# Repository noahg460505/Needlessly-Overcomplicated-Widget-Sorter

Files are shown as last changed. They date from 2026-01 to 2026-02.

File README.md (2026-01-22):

# Needlessly-Overcomplicated-Widget-Sorter

Portfolio for our widget sorter project

# Table of Contents

1. [Acknowledgments](https://github.com/noahg460505/Needlessly-Overcomplicated-Widget-Sorter/blob/main/README.md#acknowledgements)
2. [Setup](https://github.com/noahg460505/Needlessly-Overcomplicated-Widget-Sorter/blob/main/README.md#setup)
3. [Sorting](https://github.com/noahg460505/Needlessly-Overcomplicated-Widget-Sorter/blob/main/README.md#sorting)
4. [AI Acknowledgment](https://github.com/noahg460505/Needlessly-Overcomplicated-Widget-Sorter/blob/main/README.md#ai-acknowledgement)

# Acknowledgements

This widget sorter was designed, built, and tested by Noah Grimes, Yarema Mushkevych, and Markus Walker, with help from Keegan Smit, Nolan Thurman, and Claude Sonnet 4.5. Equipment was provided by Mr. Small and Mr. Cronk. 

Machining was done using equipment in the Southridge High School Engineering Lab, including

- A Carvera CNC
- A Prusa Mk3 3D-Printer
- A Laser Cutter

All CAD was done in OnShape 

All Arduino and C++ code was done in the latest version of both the Windows edition of the desktop IDE and the Linux edition of the desktop IDE. The Python code was done in Thonny on a Raspberry Pi 3B+, which was "acquired" from Mr. Cronk.

The Linear Actuator and Loctite used in this project were acquired through out-of-pocket funds. 

# Setup

(how to get this to work, hopefully)

Ensure that all LEDs on the Arduino are connected properly. This can be tested by uploading the code to the Arduino; if the wiring is successful, the LEDs should all light up. 

A standard microUSB should be connected from the Pi at port `USB0` into the Arduino. From the power strip, a 12v power supply should be connected. 
The Pi should be connected to a keyboard and monitor. We recommend using KDE Connect so that coding can be done from another device and copy-pasted into the Pi, as the Pi 3B+ is a bit slow for using an IDE, even one as simple as Thonny.

# Sorting

Start by turning on the Arduino and ensuring that it is fully active. Let the Arduino dispense one widget into the capture zone, and then take it out. Run the Python command to execute the widget sorting program. If the camera fails to connect, rerun the program. Once the Arduino is on, there is no need to restart it or turn it off. It is recommended to shine a light on the backside of the capture zone to minimize sorting errors. 

# AI Acknowledgement

The vast majority of [the Python code](code/widget_inspector.py) for this project was done by Claude Sonnet 4.5, with edits made by Noah Grimes and Keegan Smit.

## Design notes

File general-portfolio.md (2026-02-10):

# General Portfolio
This is the shared portfolio for all of us, containing the parts of the portfolio that don't differ between members of the group

## A description of the project requirements and constraints
The goal for this project was to make a device which would differentiate, sort, and count widgets based on if they have holes or not. [Good widgets](CAD/stl-files/good-widget.stl) are 3-dimensional rectangular shapes that have an off centered hole going through them and bad widgets are missing a hole. We have to load 5 good and 5 bad widgets at random and the sorter needs to count them, sort them, and know when it is done counting them after a single button press. 

## An outline of your project
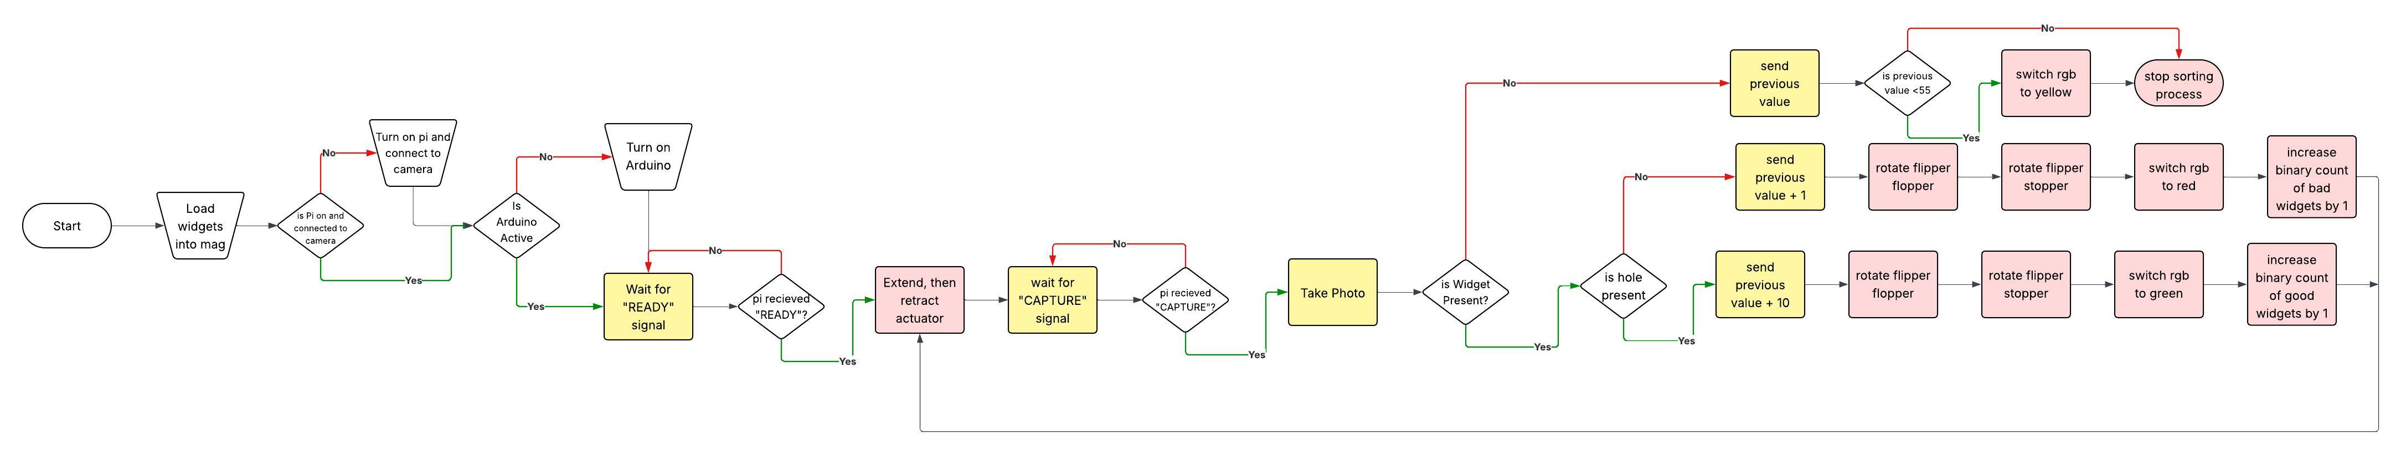
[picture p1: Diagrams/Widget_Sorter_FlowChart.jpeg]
Flowchart


## A wiring diagram - this could be hand drawn, made using software, a tinkerCAD link, etc

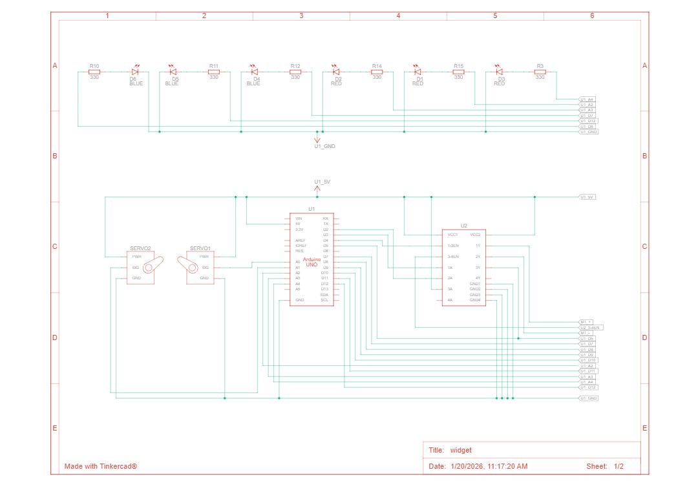
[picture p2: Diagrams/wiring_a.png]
Wiring Diagram A


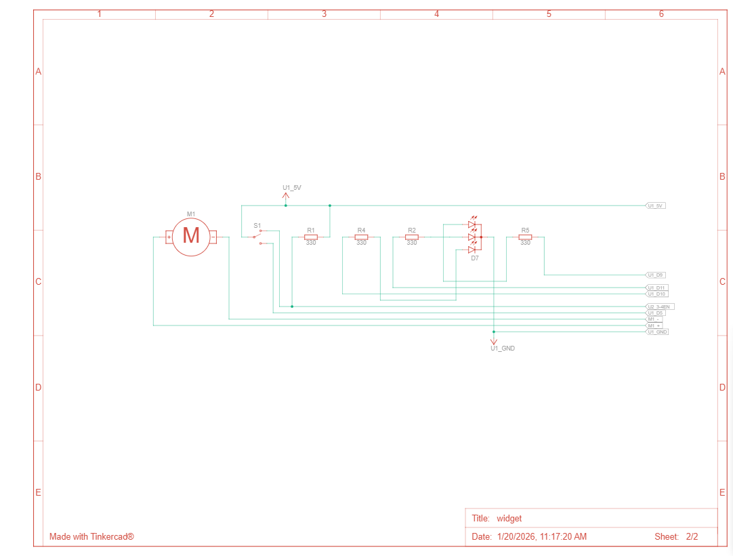
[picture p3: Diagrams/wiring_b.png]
Wiring Diagram B


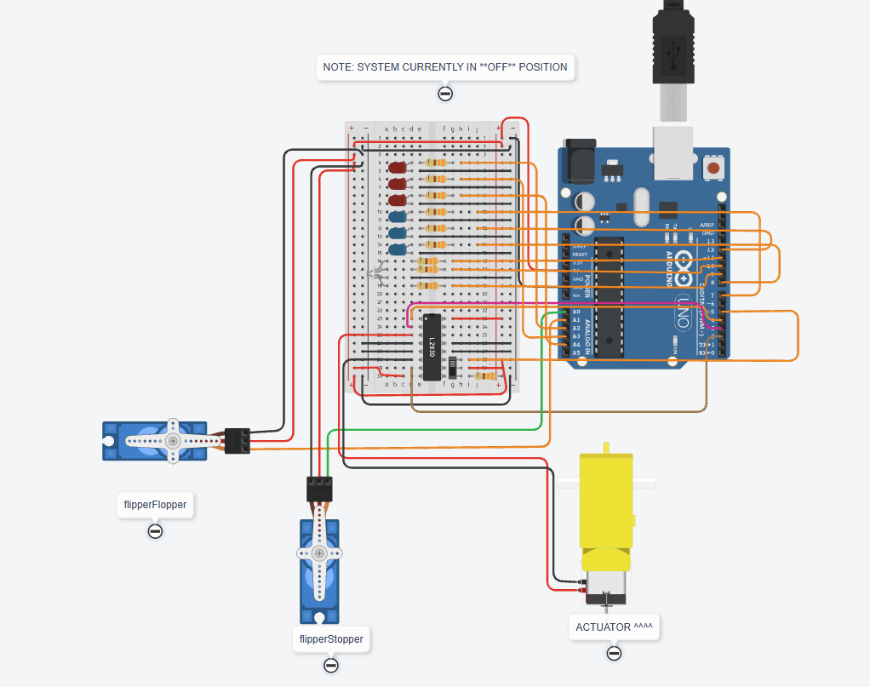
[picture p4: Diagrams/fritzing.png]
Fritzing


## A set of mechanical drawings showing components, assembly, and hardware.
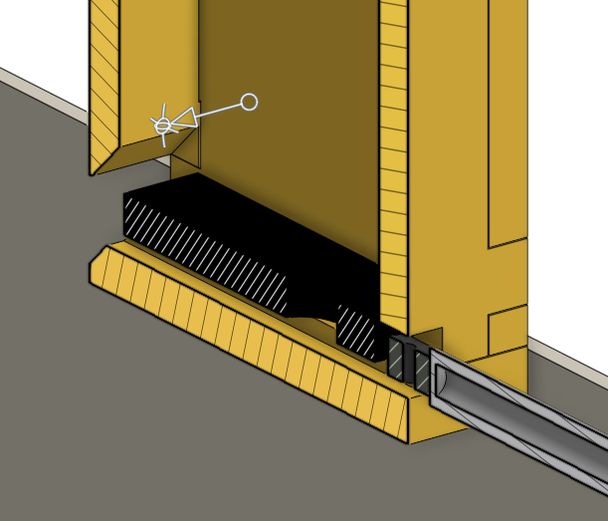
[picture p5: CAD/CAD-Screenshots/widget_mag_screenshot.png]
Widget Action


Widget MagV2.3

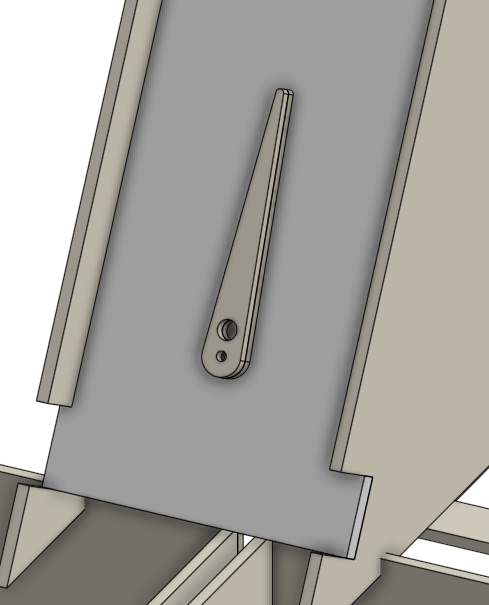
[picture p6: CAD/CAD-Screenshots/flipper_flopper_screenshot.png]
Flipper Flopper


Flipper Stopper

## A parts list
- Camera 
- Raspberry Pi
- Keyboard 
- Mouse
- Monitor
- [100mm Linear actuator](https://www.amazon.com/Electric-High-Speed-sec-Weight-Intelligent-Automation/dp/B07ZJ46947/ref=sr_1_14?th=1) 
- 2 Servo Motors
- Mounting hardware (various metric bolts)
- PLA for the prints
- 3mm wood or mdf for structure
- Arduino
- Breadboard 
- Switch 
- 3 red and 3 blue LED
- RGB LED
- Switch 
- Motor controller
- Many wires w/ Dupont connectors

## A program including header and comments
[Widget Detection Pi Code](code/widget_inspector.py)  
[Arduino Code](code/motor_control.ino)

## Any CAD models used in the project - include screen captures and a link to your drawing files
### [Onshape Link](https://cad.onshape.com/documents/1959d45d93e06fd605dded79/w/4b29a523473d3687186c98d2/e/b105ef3a0426237b67d9fdd4)  
[STL Files](CAD/stl-files)  
[Laser Cut Files](CAD/laser-files)  
[CNC Files](CAD/cnc-files)

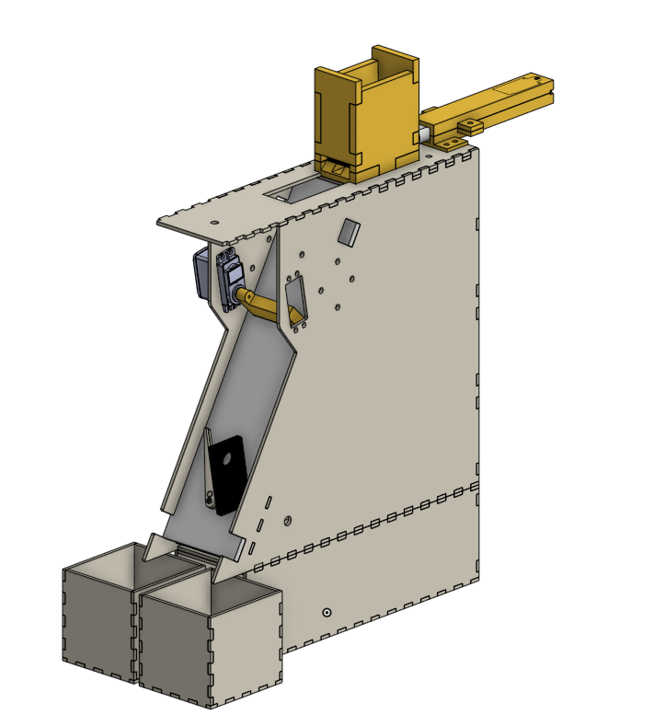
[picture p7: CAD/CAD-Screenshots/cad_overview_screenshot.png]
CAD Overview


Full Cad

## Photos of the project
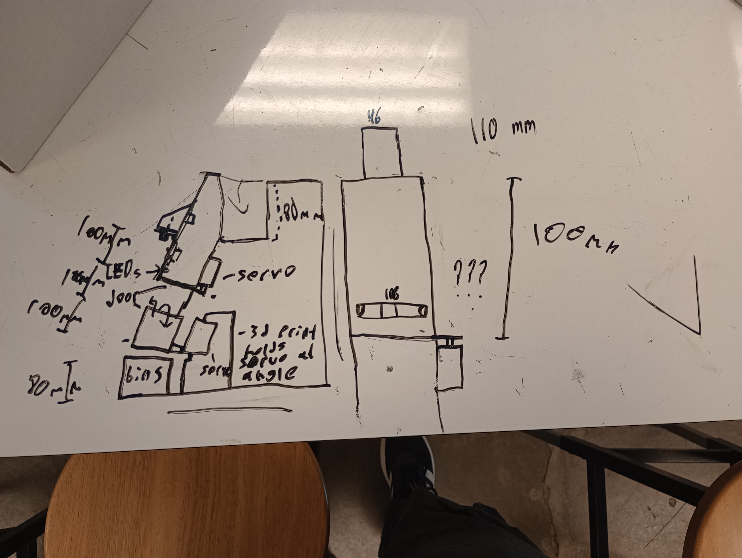
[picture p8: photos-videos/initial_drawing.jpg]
Starting Plan


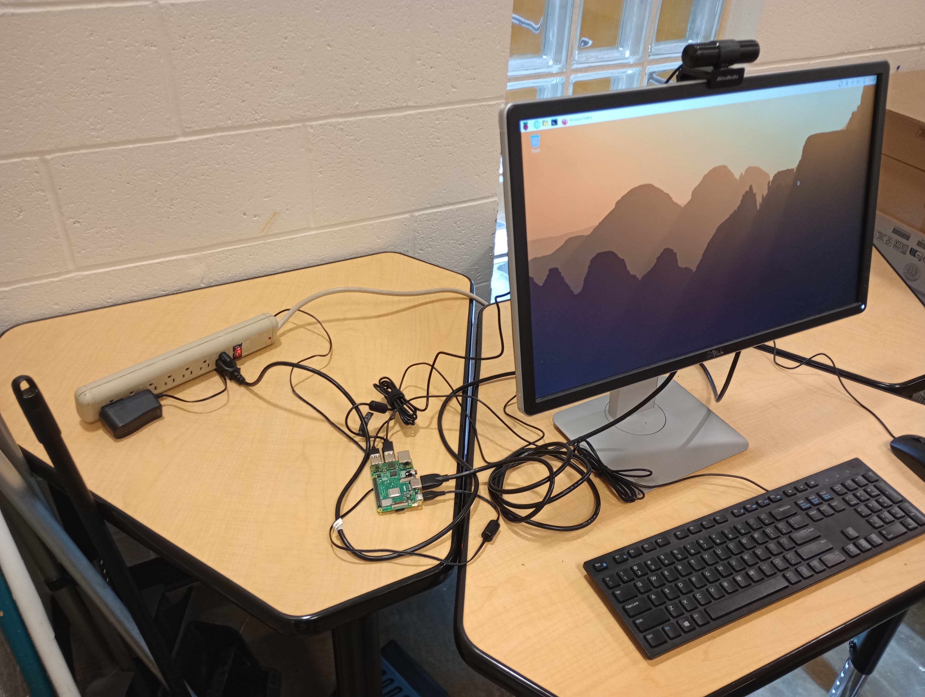
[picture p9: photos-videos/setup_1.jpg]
Pi Setup


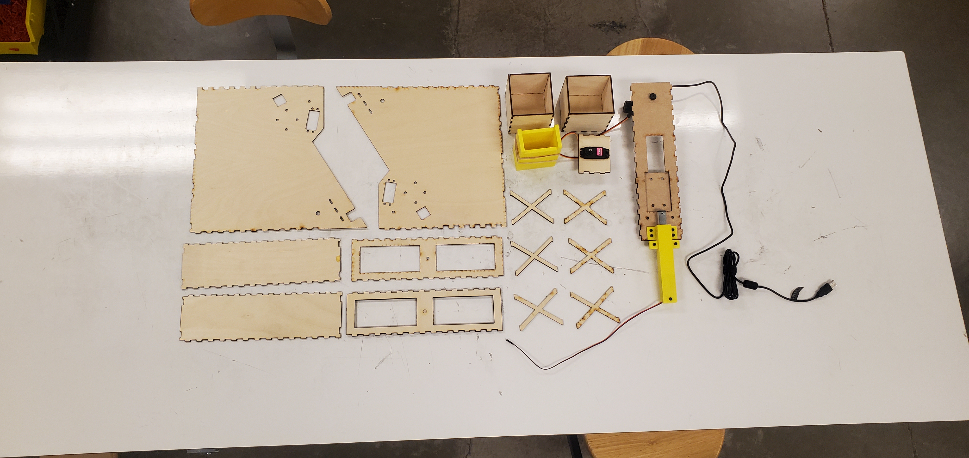
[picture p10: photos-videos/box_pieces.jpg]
Parts Laid Out


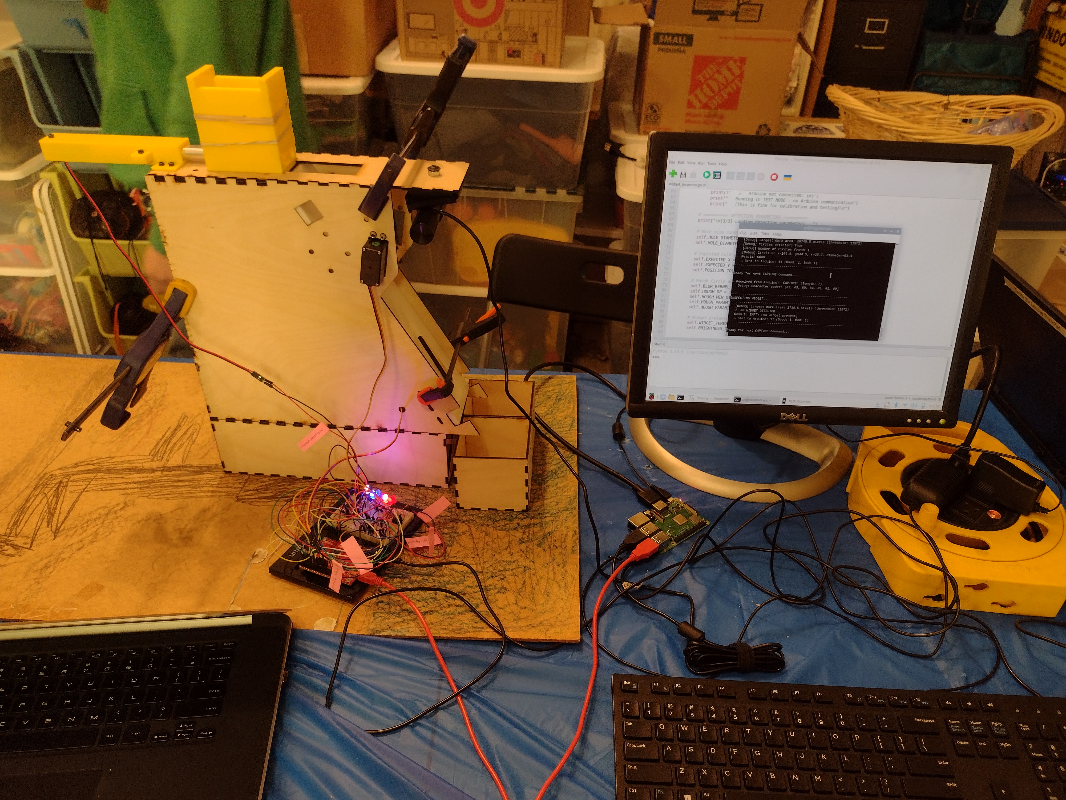
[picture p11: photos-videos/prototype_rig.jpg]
Prodotype Rig


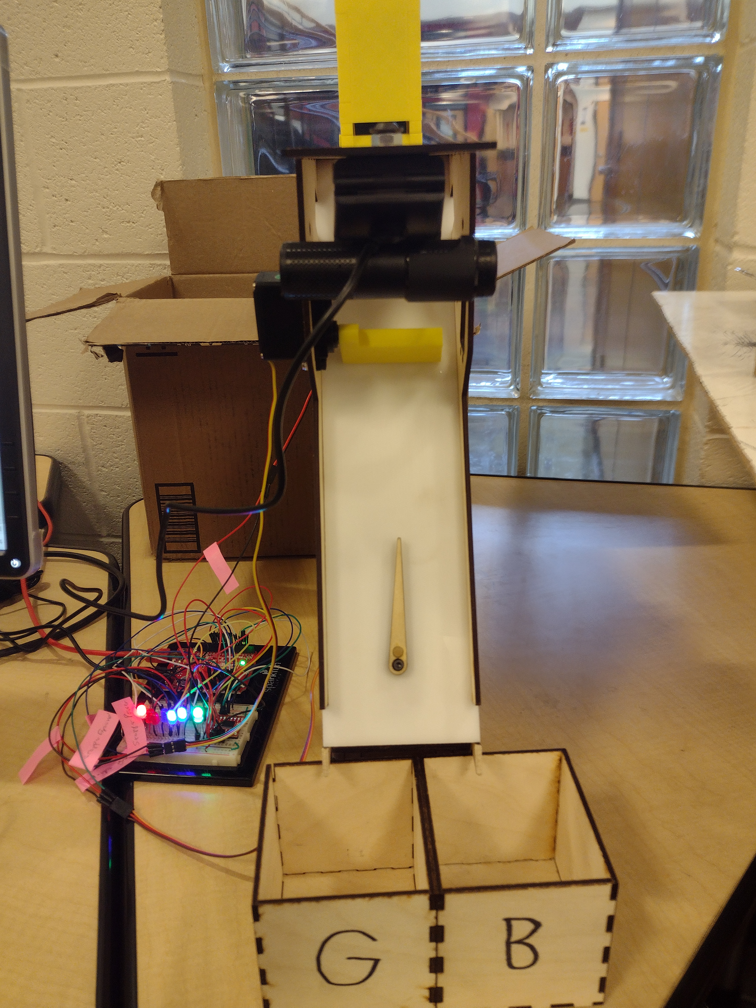
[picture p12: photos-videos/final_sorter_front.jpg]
Final Rig

## A video of it working

Prototype Test

## Reflections
[Markus Walker](Markus/markus-walker-reflection.md)

[Noah Grimes](Noah/noah-grimes-reflection.md)

[Yarema Mushkevych](Yarema/yarema-mushkevych-reflection.md)

## Any needed citations of sources

[Tinkercad Circuits Designer](https://tinkercad.com/circuits)

[Claude Sonnet](https://claude.ai)

[Arduino Forum](https://forum.arduino.cc)

[Onshape](https://cad.onshape.com)

[Download link for Arduino IDE](https://support.arduino.cc/hc/en-us/articles/360019833020-Download-and-install-Arduino-IDE)

[Thonny Download](https://thonny.org/)

[KDE Connect Download](https://kdeconnect.kde.org/download.html)

[Python Download](https://www.python.org/)

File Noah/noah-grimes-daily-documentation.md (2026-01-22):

# Day 0
## 11/12/25
Today, we began some basic planning, I was still working on my box, but we were working on coming up with ideas. We decided that instead of doing something BORING and SIMPLE, we would use a webcam attached to a Raspberry Pi and do image recognition of good and bad widgets. While this is more complicated and requires more programming, it will actually make the mechanics significantly easier.  
Initial Drawing  

# Day 1
## 11/14/25
Yesterday, I flashed a Raspbian ISO onto a microSD card that Cronk gave me, then today I went to Cronk’s classroom to grab a Pi 3B+. Today during class we got a monitor, keyboard, and mouse that were going to be thrown out with the old engineering computers. We set up a little area in the corner of the room with the Pi, monitor, keyboard, and mouse and began working on our project. After all this was done, class was basically over, so we came in during seminar to work. We started with a quick feasibility test, we had Claude Sonnet 4.5 generate some testing code, it worked pretty well, and even better when using a flashlight placed right above the camera, putting the flashlight to the side created shadows that made the recognition unreliable.

# Day 2
## 11/18/25
Today, we had Claude adjust the code so it can also detect if there is a widget there at all, as it would say no widget = bad widget. Its code sucked and it didn’t work, and my Claude free prompts had run out for the day, but because I am a PYTHON PROGRAMMING GOD I fixed the code myself, so now it works, yippee! It can fairly reliably distinguish between good, bad, and no widgets. We also started on CAD, Markus made the magazine and I made a quick widget. During seminar, we got the we got the finished magazine and started to test it, we found you needed to push the widget ALL THE WAY OUT before it would fall.

# Day 3
## 11/20/25
To make the widgets come out easier, we chamfered the edges on the output. We also made the magazine modular so it is faster to print different variants of it.

# Day 4
## 12/1/25
Today, we did a TON more CAD, we found a linear actuator part on the public parts list in Onshape and modified our magazine to fit it. Markus bought a linear actuator that can extend four inches during the break, it should arrive tomorrow.

# Day 5
## 12/3/25
We got the linear actuator, did a ton of testing with it. It doesn’t really work unless you run it at 12v, which is fine, just good to know. Markus began work on a casing for the linear actuator so we can attach it near the front instead of the back. I started work on the ramp itself.

# Day 6
## 12/5/25
Did a bunch more work on the ramp, now have the linear actuator casing, but it doesn’t key in properly in the front, the actuator gets narrower, but casing stays at a constant width. The linear actuator is only attached to the casing in the back, so it needs to be tight in the front to not be able to rotate side-to-side.

# Day 7
## 12/9/25
I realized the side walls were too tall for the MDF sheets, so I made it shorter, and adjusted things a lot. This adjustment took me the vast majority of the class time we had today.

# Day 8
## 12/11/25
Today we tested the linear actuator with the box, but with the top plate so it was at the right height. The actuator was slightly too high and started hitting the wall. We couldn’t just sand the wall a bit to give it more room, because then the actuator would hit both the bottom and the next widget above, instead of JUST the bottom widget. We made these minor corrections and started printing, we didn’t get anything else done today. Yarema and Markus helped me study for a math quiz tomorrow.

# Day 9
## 12/15/25
Today I was struggling wayyyy too much to make finger joints for the sorting bins, so I personally didn’t get much done. Today we also tested the fixed version of widget magazine, the linear actuator no longer collides with it, yippee! During seminar, we started cutting the sorting boxes on the laser cutter, they didn’t finish before the end of seminar.

# Day 10
## 12/17/25
At the beginning of class we got the flipper stopper, which Markus designed). During class, we assembled the sorting bins with wood glue. We also cut out the servo mounting bracket for the flipper flopper. Not much else done this class, we had the OSU engineering presentation today. During seminar, I was able to do the last bits of CAD for the whole structure. I designed some MDF cross members to support the structure, and we got those all cut out on the laser cutter. Virtually everything is now ready to be manufactured and assembled now, yippee!  
CAD Overview

# Day 11
## 12/19/25
Today we just cut out a bunch of the side panels and such on the laser while Yarema finished the code.

# Day 12
## 1/7/26
Today we started gluing the whole structure together and also tried to figure out the CNC to get the ramp cut, we did not get it figured out.

# Day 13
## 1/9/26
We tried to CNC, we spent 20 minutes removing the paper from the acrylic, we then realized that the keying cut by the CNC was not even slightly centered because Markus gave Mr. Small the wrong dimensions >:c

Also everything that can be glued is now glued, the whole structure can stay together (the side panel is just sitting on, since the ramp still needs to be installed).

# Day 14
## 1/13/26
Mr. Small got our ramp cut on the CNC, so today we assembled everything - still without glue - and did some testing. I ran out of time to rewrite the awful AI code, so we just had to have the AI improve it with some modifications, ran out of prompts with completely broken code though, so we came in for seminar and had Keegan help fix it with us (He is much faster at troubleshooting than me, and that code is awful to read). We got it working though, minus the Arduino communication, gotta get that working tomorrow, hopefully we finish the project in time!

# Day 15
## 1/15/26
Mr. Small spent around half of class today talking about field trips and engineering classes for next year, so we had a bit less time. We did some final testing, it didn’t work perfectly, the flipper flopper didn’t want to move. We will have to work over the long weekend.

# Day ???
## 1/19/26
Today Yarema and Markus came to my house at 9:30 AM to work on the project, we got it fully working around 2 PM, although a lot of that time was waiting for glue to dry, lyrically analyzing J-pop, and going to Walmart to get glue because all the non-tacky glue my dad had was rock solid in the bottle.  
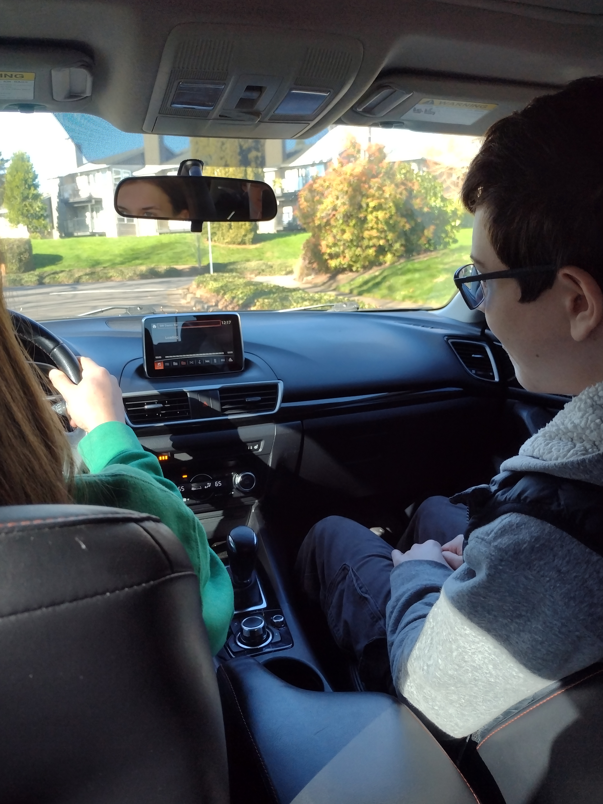
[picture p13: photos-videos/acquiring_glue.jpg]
In Markus' car going to get glue


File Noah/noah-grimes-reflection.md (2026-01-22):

# Noah Grimes' Project Reflection

## What did I do on the project?

I did the majority of the CAD for this project. I was also supposed to do the Python code, but I never really had time to write it, we ended up just using the original placeholder genAI code.

## What Challenges Did I Overcome?

Tons of things, such as the side walls being too big to laser cut, having to redo finger joints constantly, webcam being too wide to fit between side walls, and many, many more issues. Fixing the horrible AI code was also a pain, once I had to kidnap Keegan to help fix it with me during seminar.

## What Would I Do Differently?

If I were to do this project again, I would try to integrate the electronics more directly into the box. Binary display LEDs and RGB LED would be just be poking out the side of the box, would look cleaner, and they would probably have soldered connections, so less likely to get randomly unplugged, we had some issues with this. This would also include mounting the Arduino and Pi internally, just clean stuff up a bit more. I would also backlight the ramp, as this gave us much better results when we were detecting widgets in the classroom. But honestly, I'm just happy that this thing worked well enough that the only things I feel like we could've done differently to make it better were backlighting the ramp and ✨ _aesthetics_ ✨

## What Did I Learn In Project 1 That I Applied To Project 2?

By project one I'll assume you mean the useless box, since the proximity alarm project wasn't really a full-on project. The main thing I learned during the useless box project was how to do the CAD we do here in our engineering class in Onshape instead of Fusion360. I had to learn how to do finger joints, export stuff to be laser cut, CNC cut, etc. I also learned how to quickly iterate on CAD and make sure it is easy to edit in the future.

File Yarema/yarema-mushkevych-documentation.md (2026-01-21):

# Yarema Mushkevych's Daily Notebook

NOTE: Documentation isn’t 100% accurate. Some info may be missing from certain days

## Day 1 — 12/1/2025

Today, I wrote rudimentary Arduino code in TinkerCAD to detect input to the serial monitor. I designed a basic decimal to binary converter and began implementing the LEDs for the binary

Wiring

Fritzing

## Day 2 — 12/3/2025

Today, I rewired the TinkerCAD BreadBoard to fit more components. Because we’re cool and using a binary display, the LEDs take up a lot of space and RedBoard pins, so the more space we can use, the better. Using the servo.h library, I added functionality to a motor — it spins one way if the widget is good (serial monitor receives a 1) and another way if it is bad (serial monitor receives a 0) — and wired it up to the BreadBoard. I also implemented a switch that turns the entire setup on and off.

Today, Markus brought in his Linear Actuator, which is basically a gearmotor with fancy parts. Using the gearmotor design in TinkerCAD and a motor controller, I simulated a linear actuator. Currently, it’s only set to spin while the sorter is active. Next time I work on it, I’ll make it turn on and off based on a signal. 

Wiring

Fritzing

## Day 3 — 12/5/2025

Today, I reworked the code for detecting a new widget. Now, it receives a 2-digit value; the 10’s place is the number of good widgets and the 1’s place is the number of bad widgets. I added functionality for an extra servo to hold the widgets in place while the camera will take a photo.  

Wiring

Fritzing

## Day 4 — 12/9/2025

I somehow thought that VIN will magically turn 5v into 12v and that I didn’t need a separate 12v power supply. Noah pointed out my mistake, but the arduino we were using didn’t have the 12v port, so I had to transfer all of the wiring (which thankfully wasn’t that much) to a different board. We tested the actuator and it worked. Next class I plan to finish the LEDs and maybe do more servo work.

## Day 5 — 12/11/2025

I wired up the LEDs, but there were issues with the green LEDs not being bright enough, so I ended up swapping them out for blue LEDs. 

## Day 6 — 12/15/2025

I worked on code for the arduino motors. Somehow Noah thought that we needed to run 12v into the motors, but they only need like 4.5. I switched to using 5v for the motors and they worked. 

## Day 7 — 12/17/2025

Today we listened to a presentation from OSU. I converted the code into functions to make it easier to move things around. 

## Day 8 — 12/19/2025

This was the last work day before break. I finished the code, but will still need to test it with the completed sorter body. 

Wiring

Fritzing

## Day 9 — 1/7/2026

I didn’t have any more coding or wiring to do, so I helped wood glue the box together while Noah and Markus and Mr. Small tried to debug the CNC. Some guy in the class was watching Steins;Gate Ep. 12 on his laptop. Noah was very confused as to how I figured this out. 

## Day 10 — 1/9/2026

I did some more wood gluing. We got the CNC working. The protective layer took like 20 minutes to get off, but Markus gave the wrong dimensions :(. Noah made a github repository. We realized that we needed a red and green LED to show what the previous widget was (good or bad). We didn’t have room on the RedBoard so we swapped our yellow LED out for an RGB one. It did not work as expected, but I didn’t have to time to fix the issues.

## Day 11 — 1/13/2026

We got the final CNC done. I spent the entirety of class trying to fix the RGB led. I was unable to get it to work. I’m using the exact same code as in the arduino forums but it doesn’t work. I added stuff to the github at home. Keegan helped debug some of the AI code. At home I got the RGB to turn yellow(ish) when the mag was emptied but less than 10 widgets were sorted.

## Day 12 — 1/15/2026

I asked Claude and looked on the Arduino forums and figured out that I needed to change my wiring in order for the RGB to work. I changed the wiring but a lot of things broke. During seminar, I fixed the wiring issues and had the arduino send “READY” and “CAPTURE” commands to the Pi. Everything worked EXCEPT the flipperFlopper. 

## Day 13 — 1/19/2026

Today we were in Noah’s house from 9:30 – 2:00. We got the FlipperStopper working but it was janky, so we changed the initial position to 30° (center) and then 60° and 0° for good and bad widget. We took a video to prove that it worked in case it broke before tuesday. Noah didn’t have loc-tite so Marus drove us to Walmart so that we could buy some and glue the magazine together. We also finished the wood gluing. Our final test took a while since the sun was affecting our camera calibration. Noah’s dad ended up killing the sun which fixed our issue. The binary display broke near the end, so I’ll have to fix the wiring before next class

## Day 14 — 1/20/2026

Today was the last day to work. The fluorescent lights were causing issues with the threshold calibration for the image analysis software, but because that was an error that we couldn't really fix, Mr. Small just said that we didn't have to push ourselves further and that we did well. I started work on my portfolio

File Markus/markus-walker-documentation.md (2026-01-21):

# Day one 11/12/2025
Today I am starting to work on thinking about how the widget sorter is going to function. We first started thinking how we would sense if the widget is good or bad. The way we thought about how to do this was to take a picture and use machine learning to determine whether the widget is good or bad. This would effectively be a slide that would drop the widgets down, take a picture, determine if they are good or bad, and put them in the corresponding bucket. We want to make this project with the lowest amount of moving parts so less things would go wrong. In total there would be just something to make the widgets fall and something to make it go into a bucket. Today ended up being mostly a planning phase and helping Noah a little bit with the useless box.
# Day two 11/14/2025
Today we got the raspberry pi to work and connect to a monitor, keyboard, mouse, and web cam. Then once everything was working on the raspberry pi we started working on how to make code that could determine the difference between a good and bad widget by detecting a hole in the good widget and no hole as a bad widget. The problem with this is that the program thinks that the absence of a widget is a bad widget because it is just looking for holes so we need to fix that later. 
# Day three 11/18/2025
We continued planning how the widget sorter would work and we decided that we would have a process where a widget would be pushed out of a magazine onto an acrylic slide where it would hit a stopper, have a picture taken, and go into the correct spot based on what the program saw. We also got the program to tell if there is a good widget bad widget or not a widget. 
# Day four 11/20/25
Today we were working on the way that we would hold the widgets and make them go down the slide we were talking about earlier. We get the widget magazine printed that we designed last class but it has problems with how easily the widgets would come out of the magazine so we are now making a modular version of the magazine so it would take less time to print. We also started making plans for what the finished project would look like. 
# Day five 12/1/25
Today we are working on trying to find how we would make the body of the sorter and fit all of the pieces together that we need such as a linear actuator being included behind the widget mag. This is mostly a planning day with a little bit used to work on the cad for the sorter, mostly by Noah.
# Day six 12/3/25
We just got our linear actuator for pushing the widgets out of the widget mag today. I worked mostly on seeing if and how the linear actuator would fit into the project and work. So I mostly worked on the housing of the for the linear actuator and seeing how it extends and contracts. Noah also worked on the designs for the project and Yarema worked on the arduino code or the lights.
# Day seven 12/5/25
I again worked on the housing for the linear actuator because the previous design was messed up and was not made to the right size for the end of the actuator. So I fixed the design a little bit so it would work better for what we need it to do and added another set of mounting holes. That is about all that I did today.
# Day eight 12/9/25
I mostly just worked on some very minor things such as a mounting bracket for a servo motor. We were also just thinking about how the widget sorter would work and how we would be able to put together and build it. Yarema also got the linear actuator working with the red board so we are starting to get physical parts working on the project.
# Day nine 12/11/25
Today was mostly changing small things like adding 2 millimeters to the bottom of the widget mag and testing it to make sure that it would work with the linear actuator. Yarema also kept working on the arduino code for the binary lights and the motors. We now just need to start cutting things out and putting them together. 
# Day ten 12/15/25
Today was mostly getting small parts of the widget sorter to work and to make sure that it would work if we cut out the different parts of the widget sorter and put them together. I worked on planning where things would go and designing a flipper stopper to stop the widgets as they go down the slope. 
# Day eleven 12/17/25
Today in class we mostly listened to a presentation from a pair of engineering students from OSU. We did the rest of the things that needed to finish the engineering project and now we are starting to make the physical project itself. We mostly use the laser to cut out the main body of the widget sorter. 
# Day twelve 12/19/25
Today we did a very large amount of laser cutting getting every part for the body of the box. We cut out the two large side panels, the support box top and bottom and some support brackets. Yarema also finished the code and all that is left is to put everything together, do some final testing, and we should be done. 
# Day thirteen 1/7/26
Today we got back to work on the widget sorter after 2 weeks of winter break. We spent most of the day working on getting the ramp made so we can finally put together the final product and start making it work the way it is supposed to. We finished cutting out the shape of the ramp on the laser cutter and left class with almost being ready to cut out the partial depth holes on the CNC. We are planning on getting the cut on the CNC done in seminar and starting to get everything glued together. I also finished gluing the support box for the structure.
# Day fourteen 1/9/26
Today we kept working on the ramp for the widget sorter because when cutting it out with the CNC I gave slightly incorrect dimensions and it was off center. Now we are recutting the ramp to the right size. Cutting out the ramp is everything we have done today.
# Day fifteen 1/13/26
Today is the second to last day we have to work on the widget sorter. The ramp was cut out on the CNC (thank you Mr. Small) and now we are able to put everything together and start seeing how the sorter will work. We are using the python code that was generated by an LLM during the first few days we were working on this project. The code is not working at the moment because the AI either messes with the circle detection code or the circle placement code. This means either it detects where the circle is and thinks it is in the wrong place, or it can’t detect the circle which we will work on fixing during the seminar. 
# Day sixteen 1/15/26
Today we are mostly trying to get everything done and working but the arduino code is being worked on in order to get the motors and timings correct. The code on the Pi is working as it should be and always seeing the widgets as they should be. We hope to have the widget sorter done in seminar so that it works in the proper way. 
# Day seventeen last day 1/19/26
I went to Noah’s house at 9:30am to work on the widget sorter and make sure that it was ready and worked as it should. We got it working consistently with the 2 test widgets we were using, meaning we went on to gluing everything together and sanding parts that did not work according to plan.

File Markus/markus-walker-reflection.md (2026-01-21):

# Markus’ Widget Sorter Reflection 

## My work on the widget sorter
I worked on the logistics, cutting/printing parts out, and minor amounts of CAD. Logistics include planning how we would detect widgets, finding the workable dimensions for the parts that we made, and finding how to fix problems that arise. I spent a large amount of my time around the middle of the assignment taking the files from the CAD that [Noah](Noah) was working on using the laser cutter or printer to make it then see how it works with other things we made. The minor amounts of CAD that I worked on were the [flipper stopper](CAD/stl-files/flipper_stopper.stl), [linear actuator housing](CAD/stl-files/linear-actuator-housing.stl), the [servo mounting bracket](CAD/laser-files/servo-motor-bracket.dxf), and the first version of the [widget mag](CAD/stl-files/widget-mag-v2.3.stl).

## What challenges did you have to overcome?
The project was relatively straight forward apart from the lack of time we had and problems with making parts. Every class and every advisory we worked on the widget sorter and even then we had to take it home in order to finish it. We did end up making it so that it would function in a mostly consistent way on Monday 1/19/2026 after around 3.5 hours of work. The second challenge that we had to overcome was issues with measurements and use of tools. An example of this was that I mistakenly gave Mr. Small the wrong measurements on a part we needed to use the CNC on making that part eventually take 2 days to complete. With the dedication of Mr. Small finding out what was wrong and fixing the issue we were able to complete the project in a reasonable amount of time. 

## What would you do differently? 
I wish that when working on this project I had the skill to design CAD in a more efficient and timely manner. I didn’t have the technical ability at the time to make a widget sorter that was segmented and be able to do it during a class, this is why I am very happy that Noah was able to do that. Another thing that I could have done differently was do more of the technical operations relating to the raspberry pi and arduino but I left that to the more experienced [Noah](Noah) and [Yarema](Yarema).

## What Did I Learn In Project 1 That I Applied To Project 2?
During the widget sorter project I learned that it was very valuable to make the CAD of the object that you are planning to make before you actually make the box itself. This design that we had for the widget sorter was very useful for making sure that everything fit together how it should and allowed for changes along the way.

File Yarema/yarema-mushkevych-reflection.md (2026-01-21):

# Yarema Mushkevych's Project Reflection

This is my reflection for the widget sorter project

## What Challenges Did I Overcome?

During this project, I helped with the wiring and Arduino code. In the wiring department, I mainly had to overcome issues with a lack of space on the breadboard and figuring out how to wire everything up. In the coding department, I learned how to program servos and how to better structure my code by using functions instead of one giant main line. 

## What Would I Do Differently?

If I were to do this project again, I'd definitely solder the LEDs so that I could free up space on the breadboard. I'd see if I could make the wiring more compact and not as prone to breaking as it is right now. Perhaps I'd switch from LEDs to an LCD display so that I could display more than just a binary count.

## What Did I Learn In Project 1 That I Applied To Project 2?

In 'Project 1,' I learned how to write code for a Hobby Gearmotor, which helped me then write the code for the linear actuator, which is effectively the same thing. My previous experience with Arduino projects in general allowed me to understand how wiring and code would work, which helped speed up the construction process.

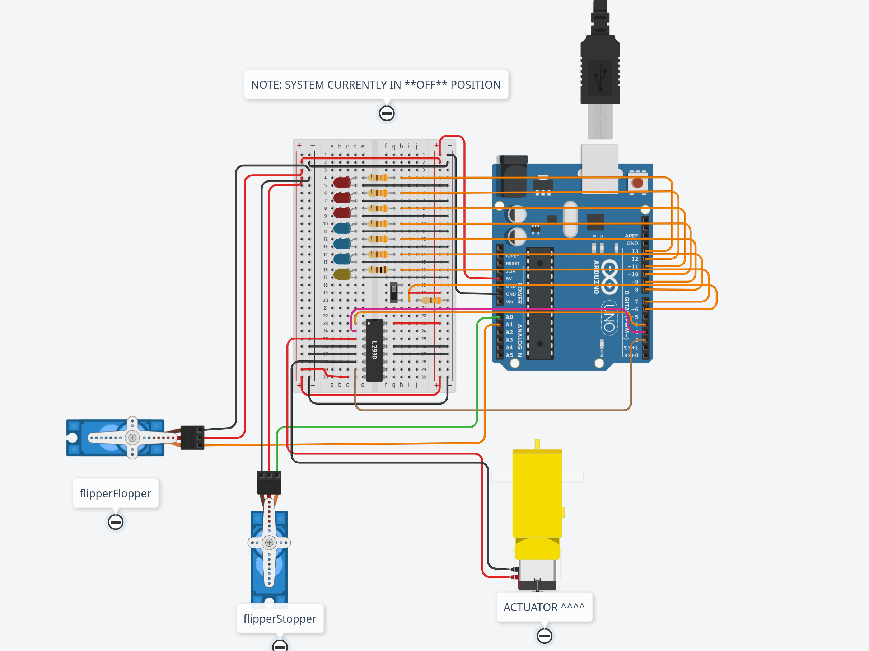
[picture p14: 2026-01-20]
Diagrams/12_19-Fritzing.png

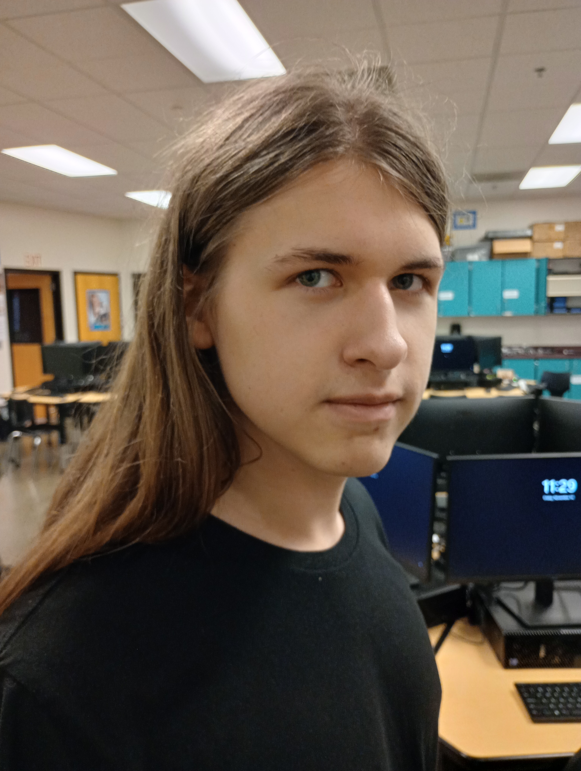
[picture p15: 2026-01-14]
photos-videos/markus.jpg

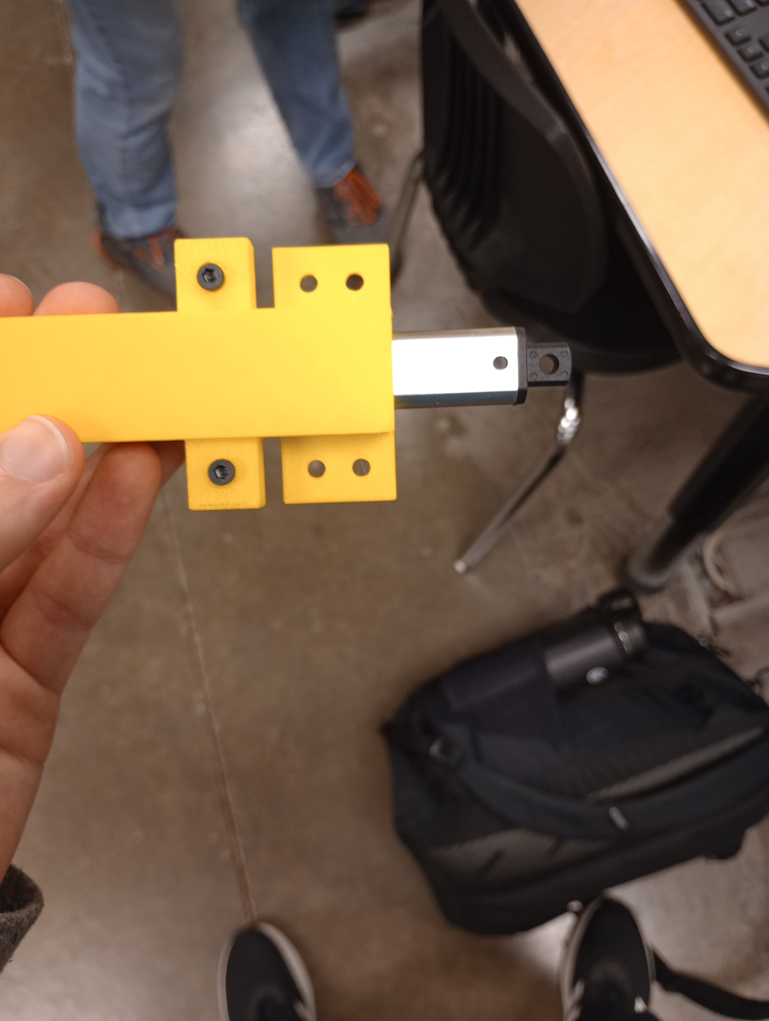
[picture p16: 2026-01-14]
photos-videos/actuator_3.jpg

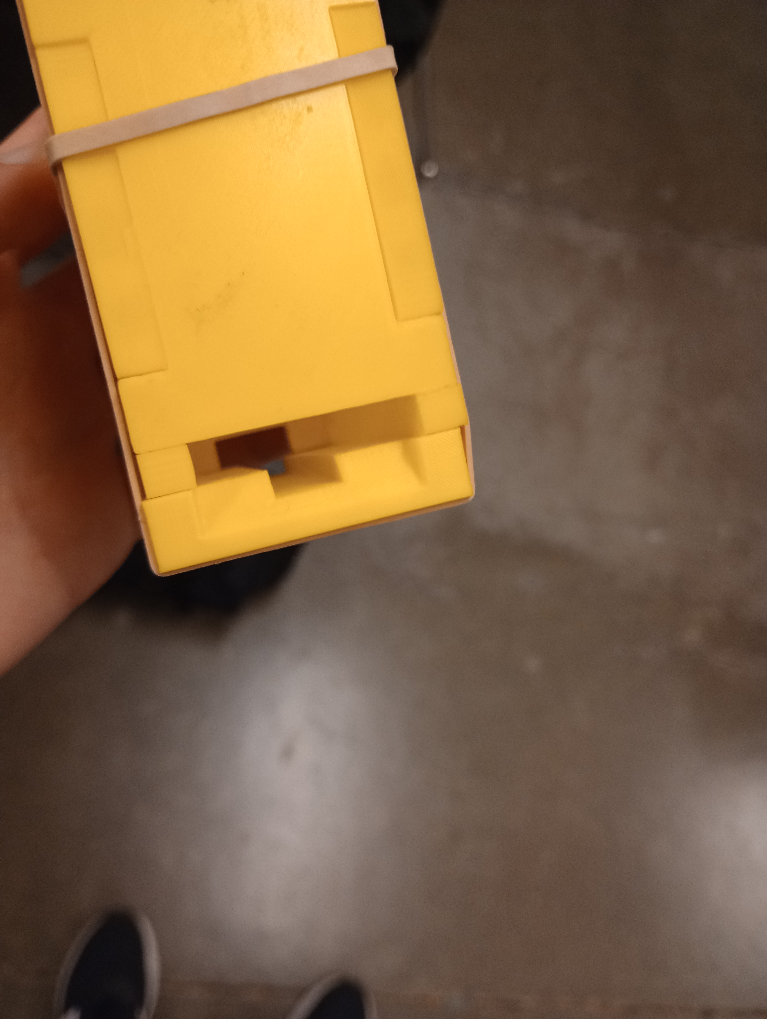
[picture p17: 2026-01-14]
photos-videos/widget_mag_2.jpg

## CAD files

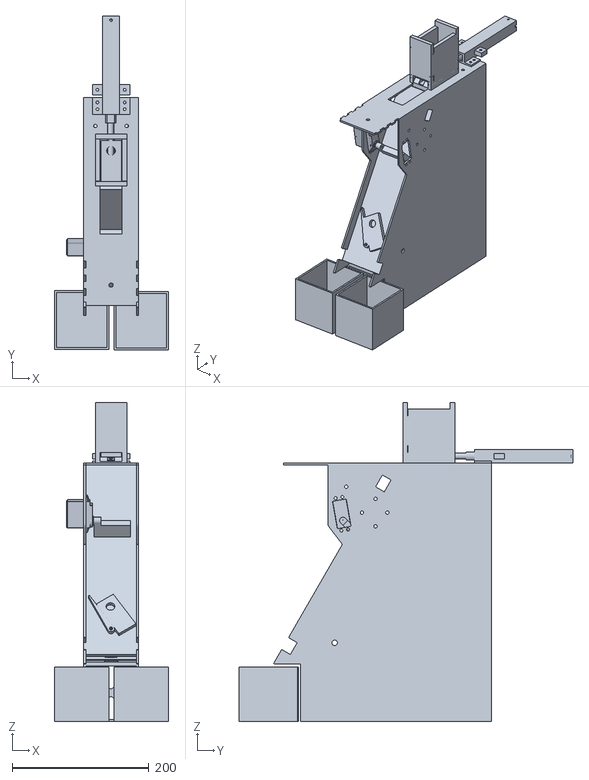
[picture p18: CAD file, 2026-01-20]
CAD/stl-files/full-assembly.stl
167.0 x 489.1 x 467.8

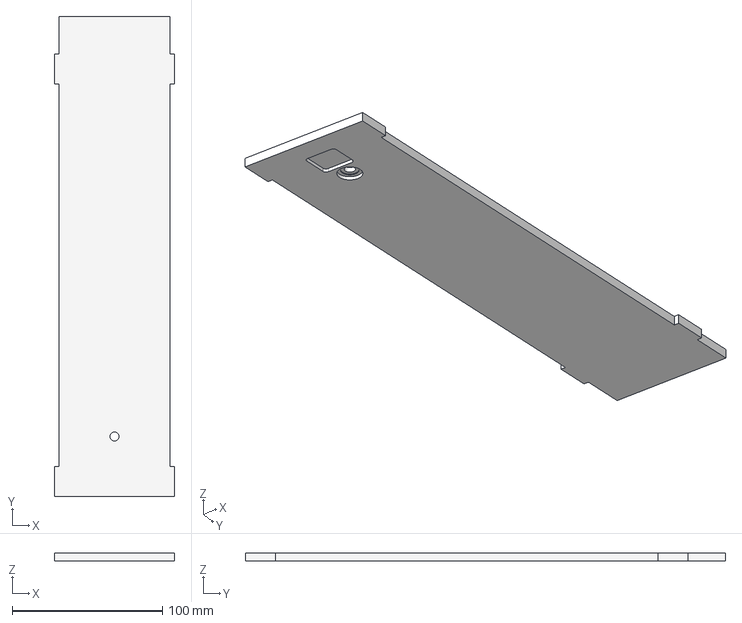
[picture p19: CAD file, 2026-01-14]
CAD/cnc-files/ramp.step
80.0 x 320.0 x 5.30 mm

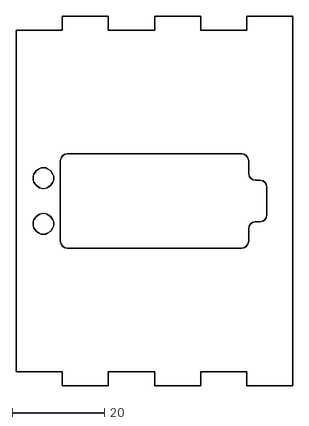
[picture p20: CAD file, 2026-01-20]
CAD/laser-files/servo-motor-bracket.dxf
60.0 x 80.0

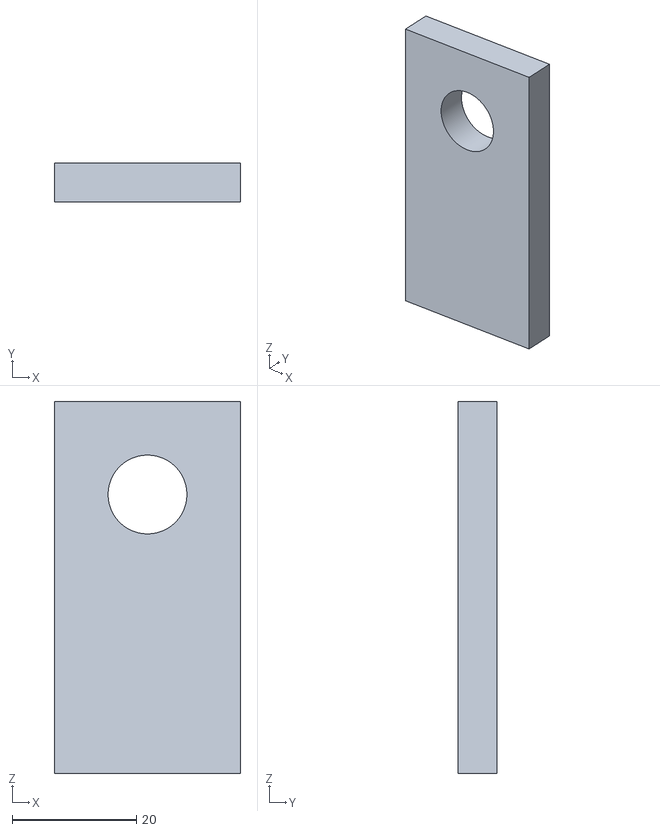
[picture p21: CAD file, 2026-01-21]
CAD/stl-files/good-widget.stl
30.0 x 6.35 x 60.0

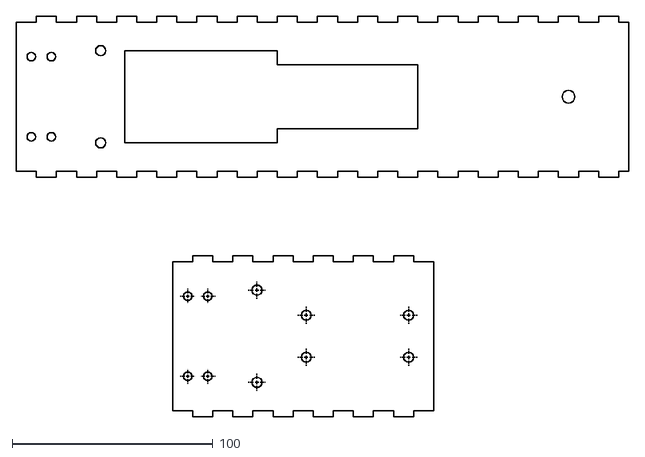
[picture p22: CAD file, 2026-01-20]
CAD/laser-files/body-top-and-toppier.dxf
305.0 x 199.3

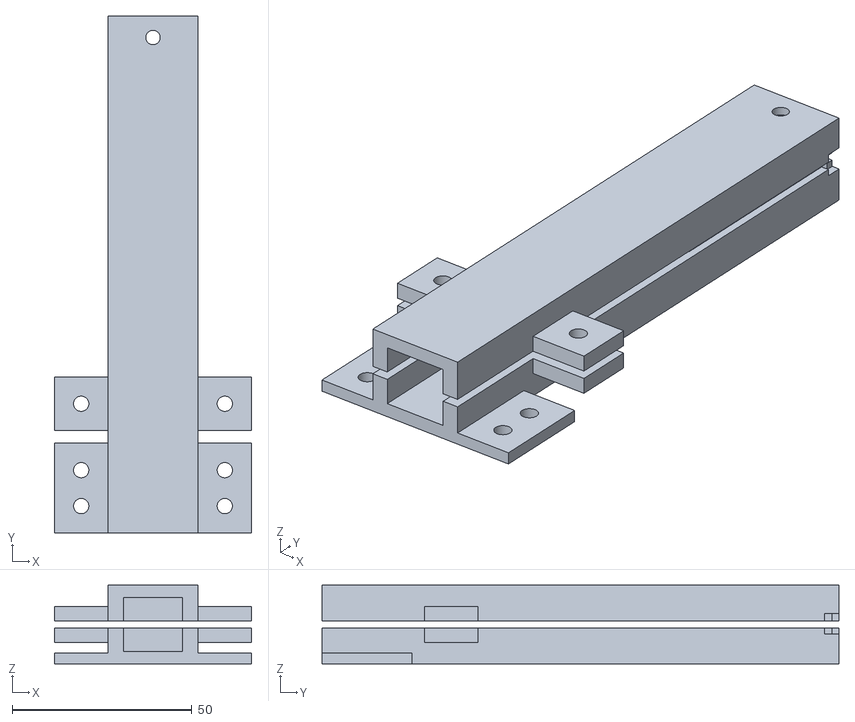
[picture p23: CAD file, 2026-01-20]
CAD/stl-files/linear-actuator-housing.stl
55.0 x 144.0 x 22.0

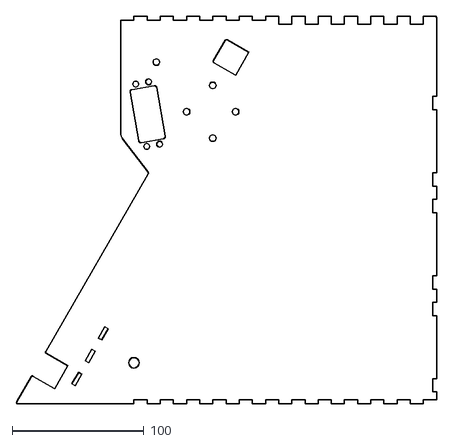
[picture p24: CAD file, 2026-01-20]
CAD/laser-files/2x - body-side-wall.dxf
319.3 x 294.4

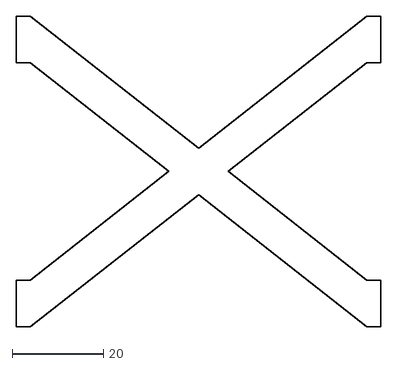
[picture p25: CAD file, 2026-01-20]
CAD/laser-files/5x - cross-member.dxf
80.0 x 68.2

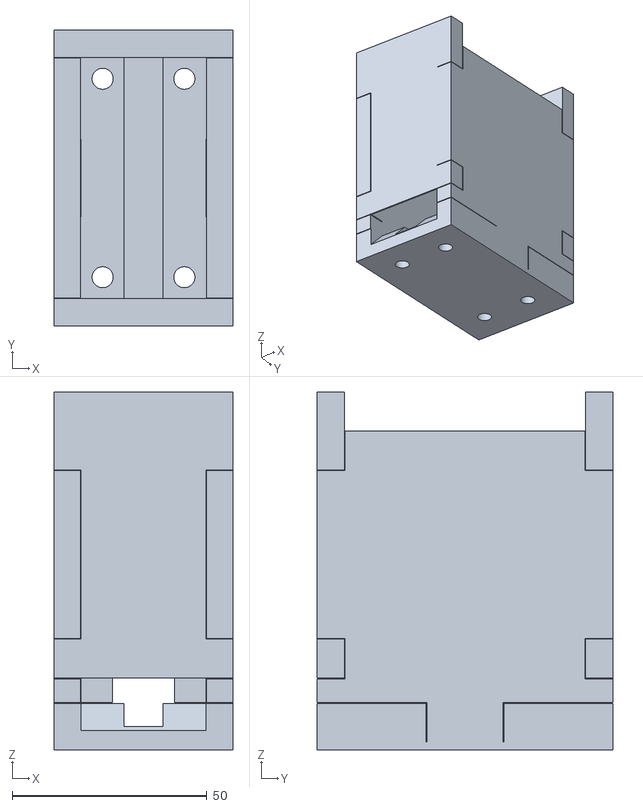
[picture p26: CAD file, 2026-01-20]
CAD/stl-files/widget-mag-v2.3.stl
46.0 x 76.0 x 92.0

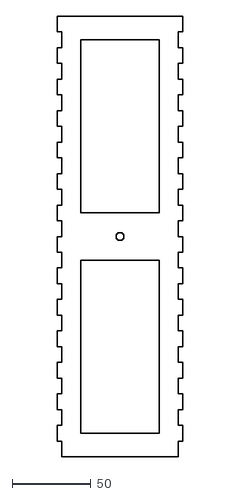
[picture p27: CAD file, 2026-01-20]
CAD/laser-files/3x - support-box-base.dxf
80.0 x 280.0

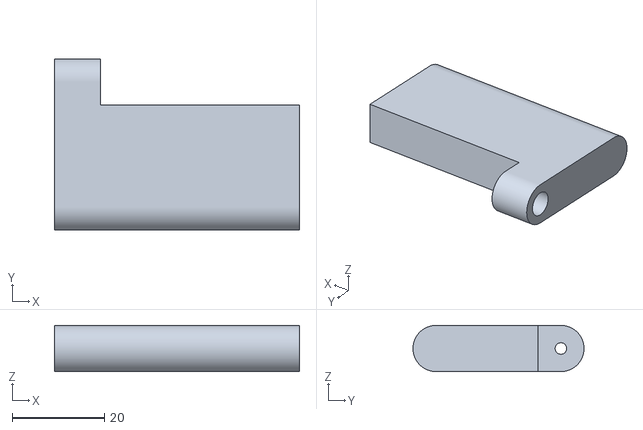
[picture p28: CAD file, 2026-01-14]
CAD/stl-files/flipper_stopper.stl
53.0 x 37.0 x 10.0

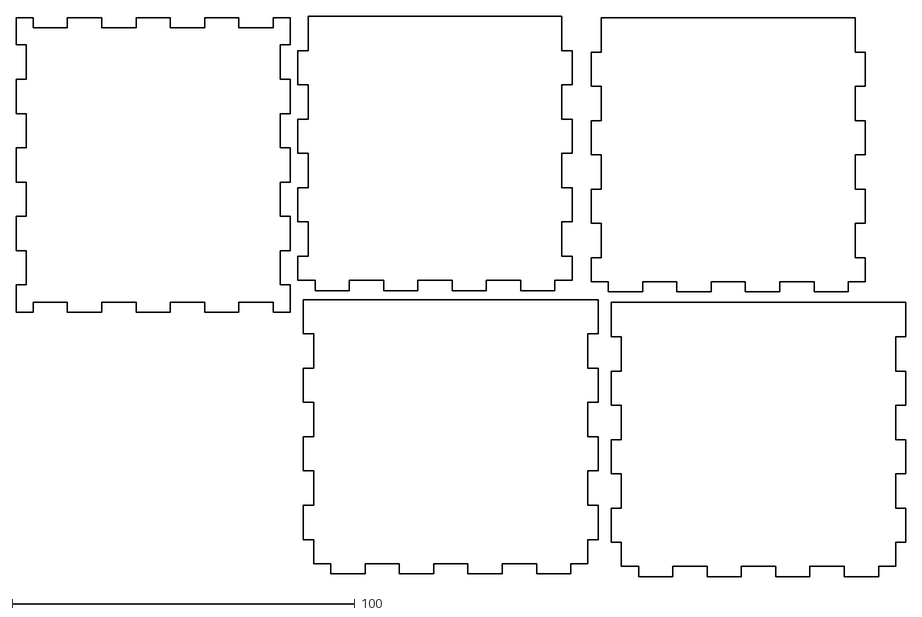
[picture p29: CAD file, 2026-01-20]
CAD/laser-files/2x - sorting-box.dxf
259.6 x 163.5

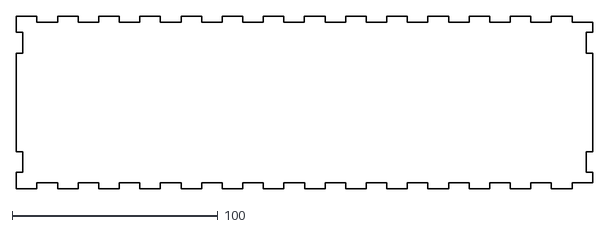
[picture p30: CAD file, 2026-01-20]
CAD/laser-files/2x - support-box-side-wall.dxf
280.0 x 84.0

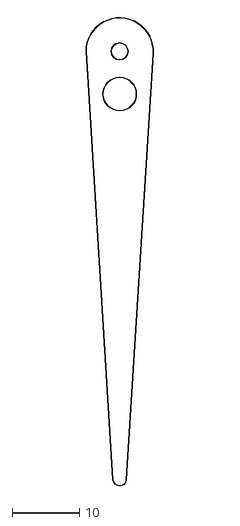
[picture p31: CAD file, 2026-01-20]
CAD/laser-files/toppier-flipper-flopper.dxf
10.1 x 70.1

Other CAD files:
CAD/laser-files/flipper-flopper.dxf

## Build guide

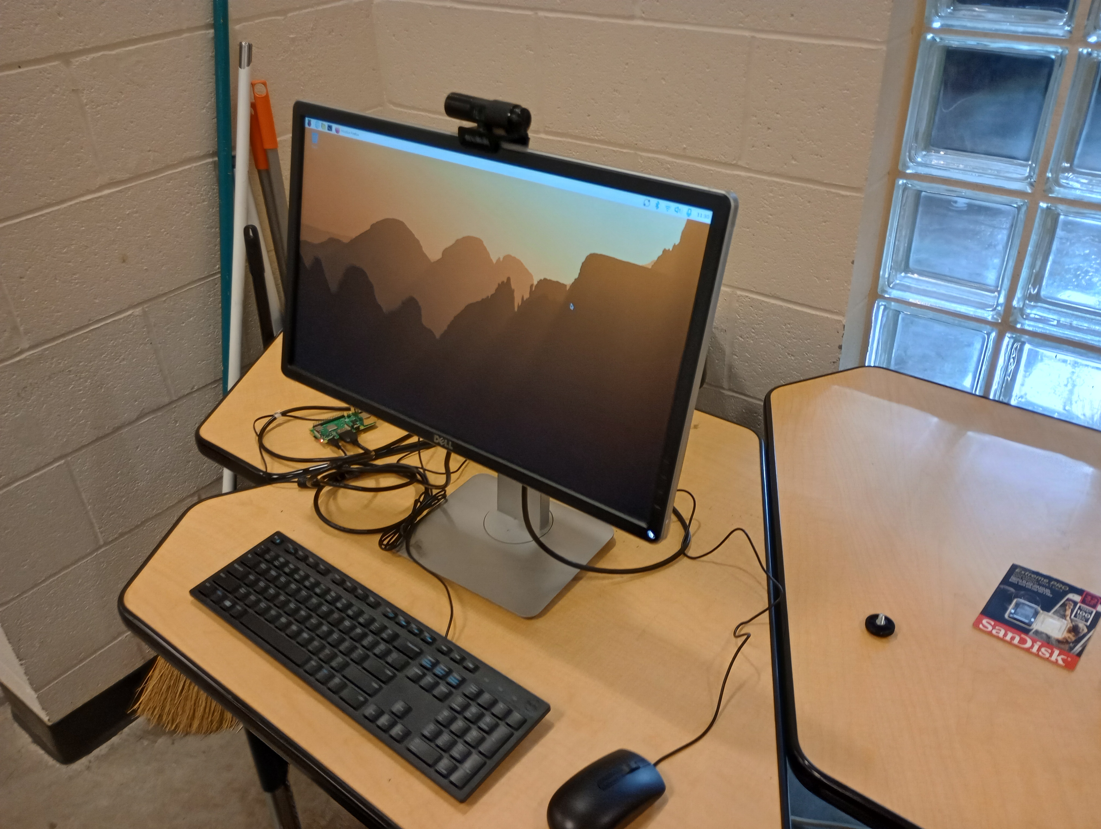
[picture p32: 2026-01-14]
photos-videos/setup_2.jpg

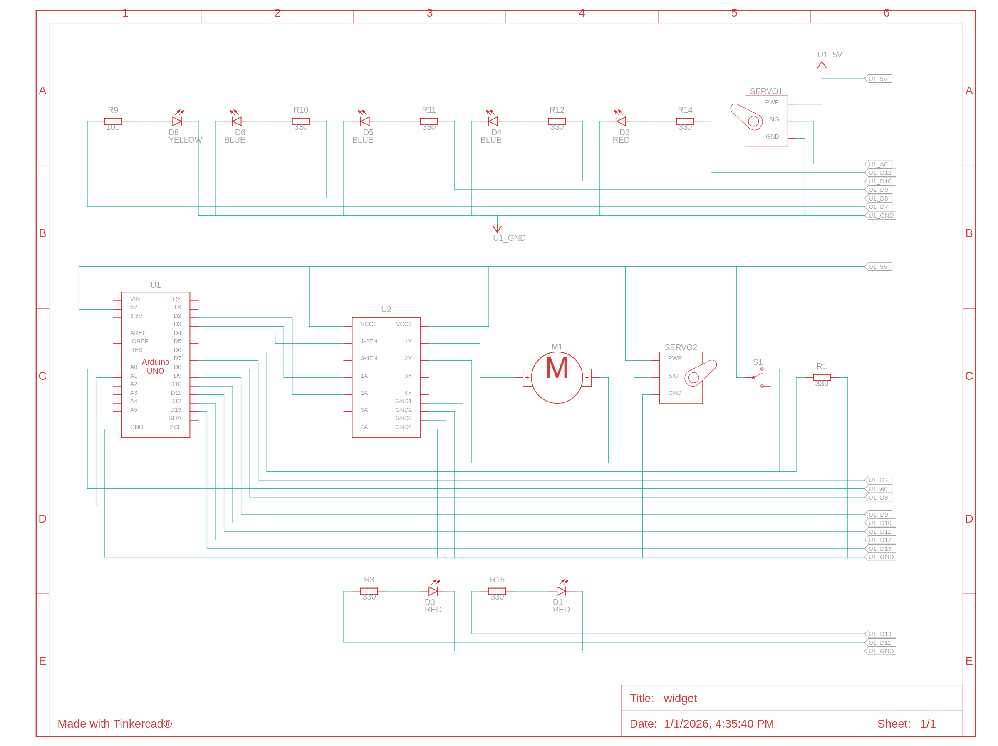
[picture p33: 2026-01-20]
Diagrams/12_19-Wiring.png

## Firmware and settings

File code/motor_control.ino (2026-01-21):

/*
Code to rotate servos, light up LEDs, and actuate the actuator

This code is designed to run on an Arduino Uno, and can be uploaded with a standard microUSB.

This code was designed primarily by Yarema Mushkevych, with minor guidance from Noah Grimes, Markus Walker, Keegan Smit, The Arduino Forums, and Claude Sonnet 4.5
*/

// define the Servo library and setup constants
#include <Servo.h>
int goodWidgets = 0;
int badWidgets = 0;
const int greenLEDpins[3] = {7, 12, 8};
const int redLEDpins[3] = {A2, A3, A4};
const int rgbLEDpins[3] = {9, 10, 11};
const int servoPins[2] = {A0, A1};
const int switchPin = 5;
const int actuatorPins[3] = {4,3,2};
int previousValue = 0; 
int widgets = -1; // starts at -1 to not conflict with other code
Servo flipperStopper;
Servo flipperFlopper;
const int goodWidgetAngle = 0;
const int badWidgetAngle = 60;
const int flopperStart = 30;

void setup() {
  // define pins
  pinMode(actuatorPins[0], OUTPUT);
  pinMode(actuatorPins[1], OUTPUT);
  pinMode(actuatorPins[2], OUTPUT);
  pinMode(rgbLEDpins[0], OUTPUT);
  pinMode(rgbLEDpins[1], OUTPUT); 
  pinMode(rgbLEDpins[2], OUTPUT);
  pinMode(greenLEDpins[0], OUTPUT);
  pinMode(greenLEDpins[1], OUTPUT);
  pinMode(greenLEDpins[2], OUTPUT);
  pinMode(redLEDpins[0], OUTPUT);
  pinMode(redLEDpins[1], OUTPUT);
  pinMode(redLEDpins[2], OUTPUT);
  pinMode(switchPin, INPUT_PULLUP);
  // fully retract actuator
  digitalWrite(actuatorPins[2], LOW); 
  digitalWrite(actuatorPins[1], HIGH);
  analogWrite(actuatorPins[0], 255);
  delay(2000);
  // write servos to the proper positions
  flipperStopper.attach(servoPins[0]);
  flipperFlopper.attach(servoPins[1]);
  flipperStopper.write(0);
  flipperFlopper.write(flopperStart);
  Serial.begin(9600); // define serial
  Serial.println("READY"); // send "READY" signal to begin 
  if (digitalRead(switchPin) == HIGH) {
    indicateActiveAndReady(); // flash all LEDs on (and then off) to indicate that the Arduino is active
  }
  delay(3000); // wait for Pi to finish calibration (if needed)
}

void loop() {
  if (digitalRead(switchPin) == HIGH) {
    // if the arduino is on:
    if (widgets != 0) {
      extendActuator(); // push widget into camera zone
      retractActuator(); // retract actuator in preparation for next widget
    }
    Serial.println("CAPTURE"); // tell PI
    widgets = Serial.parseInt(); //widgets is the next value sent to the serial. First integer is good widget count, second is bad widget count 
    if (widgets != 0) {
      // if a widget has been detected (prevents actuator from infinitely moving):
      incrementWidgetCount(widgets, rgbLEDpins[0], rgbLEDpins[1], rgbLEDpins[2]); // increase widget count (either good or bad) accordingly
      flipperStopperDown(); //lower flipperStopper in preparation for next widget
      binaryDisplay(goodWidgets, badWidgets); // update the binary display
      flipperFlopper.write(flopperStart); // reset flipperFlopper
    } else {
      retractActuator(); // otherwise, retract the actuator
    }
  } else {
    retractActuator();
    delay(1500);
    stop(0, rgbLEDpins[0], rgbLEDpins[1], rgbLEDpins[2]);
  }
}
void incrementWidgetCount(int widgets, int redPin, int greenPin, int bluePin) {
  if (widgets == previousValue+1) {
    // this is a bad widget
    badWidgets++;
    delay(500);
    // switch RGB LED to display red
    analogWrite(redPin, 255);
    analogWrite(greenPin, 0);
    analogWrite(bluePin, 0);
    flipperFlopperRotation(0); //rotate flipperFlopper to sort widgets into bad bin
    delay(500);
    flipperStopperUp(); //allow widget to pass into sorting block
    delay(2500);
    flipperFlopper.write(flopperStart); //reset FlipperFlopper
  } else if (widgets == previousValue+10) {
  	// this is a good widget
    goodWidgets++;
    delay(500);
    //switch RGB LED to display green
    analogWrite(redPin, 0);
    analogWrite(greenPin, 255);
    analogWrite(bluePin, 0);
    flipperFlopperRotation(1); //rotate flipperFlopper to sort widgets into good bin
    delay(500); 
    flipperStopperUp(); //allow widget to pass into sorting block
    delay(2500);
    flipperFlopper.write(flopperStart); //reset FlipperFlopper
  } else if ((widgets == previousValue) and (widgets > 0)) {
    // if no widget detected:
    if ((goodWidgets + badWidgets) < 10) {
      // if less than 10 widgets were sorted
      retractActuator();
      delay(1500);
      stop(1, rgbLEDpins[0], rgbLEDpins[1], rgbLEDpins[2]); //turn off sorter, BUT turn RGB yellow
    } else {
      retractActuator();
      delay(1500);
      stop(0, rgbLEDpins[0], rgbLEDpins[1], rgbLEDpins[2]); // turn off sorter, and DON'T turn RGB yellow
    }
  }
  if (widgets > 0) {
    previousValue = widgets; //update previous value, but only if a widget was actually detected
  }

  
}
void binaryDisplay(int goodWidgetCountForBinary, int badWidgetCountForBinary) {
  // define lists to store binary counts
  int binaryGood[3]; 
  int binaryBad[3];
 
  //decimal to binary
  for (int i = 0; i < 3; i++) {
   binaryGood[i] = goodWidgetCountForBinary % 2;
   goodWidgetCountForBinary /= 2;  
   binaryBad[i] = badWidgetCountForBinary % 2;
   badWidgetCountForBinary /= 2;
  }
  //if pos in array is 1, light on, else off
  for (int i = 0; i < 3; i++) {
    if (binaryGood[i] == 1) {
    	digitalWrite(greenLEDpins[2-i], HIGH);
    } else {
    	digitalWrite(greenLEDpins[2-i], LOW);
    }
  }
  for (int i = 0; i < 3; i++) {
    if (binaryBad[i] == 1) {
        digitalWrite(redLEDpins[2-i], HIGH);
    } else {
        digitalWrite(redLEDpins[2-i], LOW);
    }
  }	
}
void flipperStopperUp() {
  flipperStopper.write(170);
  delay(1000);
}
void flipperStopperDown() {
  flipperStopper.write(0);
  delay(1000);
}
void extendActuator() {
  digitalWrite(actuatorPins[2], HIGH);
  digitalWrite(actuatorPins[1], LOW);
  analogWrite(actuatorPins[0], 255);
  delay(3500);
  digitalWrite(actuatorPins[2], LOW);
  digitalWrite(actuatorPins[1], LOW);
  analogWrite(actuatorPins[0], 0);
  delay(750);
}
void retractActuator() {
  digitalWrite(actuatorPins[2], LOW);
  digitalWrite(actuatorPins[1], HIGH);
  analogWrite(actuatorPins[0], 255);
  delay(3500);
  digitalWrite(actuatorPins[2], LOW);
  digitalWrite(actuatorPins[1], LOW);
  analogWrite(actuatorPins[0], 0);
  delay(750);
}
void flipperFlopperRotation(int widgetType) {
  // rotate flipperFlopper as needed
  if (widgetType == 1) {
    // this is a good widget
    flipperFlopper.write(goodWidgetAngle);
   } else if (widgetType == 0) {
    // this is a bad widget
    flipperFlopper.write(badWidgetAngle);
   }
}
void indicateActiveAndReady() {
  // briefly flash all LEDs on and then off to indicate 'active and ready'
  digitalWrite(greenLEDpins[0], HIGH);
  digitalWrite(greenLEDpins[1], HIGH);
  digitalWrite(greenLEDpins[2], HIGH);
  digitalWrite(redLEDpins[0], HIGH);
  digitalWrite(redLEDpins[1], HIGH);
  digitalWrite(redLEDpins[2], HIGH);
  analogWrite(rgbLEDpins[0], 255);
  analogWrite(rgbLEDpins[1], 255);
  analogWrite(rgbLEDpins[2], 255);
  delay(1000);
  digitalWrite(greenLEDpins[0], LOW);
  digitalWrite(greenLEDpins[1], LOW);
  digitalWrite(greenLEDpins[2], LOW);
  digitalWrite(redLEDpins[0], LOW);
  digitalWrite(redLEDpins[1], LOW);
  digitalWrite(redLEDpins[2], LOW);
  analogWrite(rgbLEDpins[0], 0);
  analogWrite(rgbLEDpins[1], 0);
  analogWrite(rgbLEDpins[2], 0);
  delay(500);
}
void stop(int hasYellow, int redPin, int greenPin, int bluePin){
  while (true) {
    digitalWrite(actuatorPins[2], LOW);
    digitalWrite(actuatorPins[1], LOW);
    analogWrite(actuatorPins[0], 0);
    goodWidgets = 0;
    badWidgets = 0;
    // determine whether to keep RGB as yellow or shut it off completely
    if (hasYellow == 1) {
      analogWrite(redPin, 255);
      analogWrite(greenPin, 255);
      analogWrite(bluePin, 10);
    } else if (hasYellow == 0) {
      digitalWrite(greenLEDpins[0], LOW);
      digitalWrite(greenLEDpins[1], LOW);
      digitalWrite(greenLEDpins[2], LOW);
      digitalWrite(redLEDpins[0], LOW);
      digitalWrite(redLEDpins[1], LOW);
      digitalWrite(redLEDpins[2], LOW);
    }
  }
}

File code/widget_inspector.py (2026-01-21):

#!/usr/bin/env python3
"""
Widget Sorting Vision System for Raspberry Pi
Detects holes in acrylic widgets using OpenCV
Communicates with Arduino via serial for automated sorting

Usage:
  python3 widget_inspector.py                    # Run with Arduino (auto mode)
  python3 widget_inspector.py --calibrate        # Calibration mode
  python3 widget_inspector.py --manual           # Manual testing mode
  python3 widget_inspector.py --port /dev/ttyUSB0  # Specify Arduino port

Vast majority of code by Claude Sonnet 4.5, with edits by Keegan Smit and Noah Grimes  
"""

import cv2
import numpy as np
import serial
import time
import sys

class WidgetInspector:
    def __init__(self, serial_port='/dev/ttyACM0', camera_id=0):
        """
        Initialize the widget inspector system
        
        Args:
            serial_port: Path to Arduino serial port (try /dev/ttyACM0, /dev/ttyUSB0, /dev/ttyACM1)
            camera_id: Camera device ID (usually 0, try 1 if camera not found)
        """
        print("="*60)
        print("WIDGET INSPECTOR INITIALIZATION")
        print("="*60)
        
        # ========== CAMERA SETUP ==========
        print("\n[1/3] Setting up camera...")
        self.camera = cv2.VideoCapture(camera_id)
        
        if not self.camera.isOpened():
            print(f"ERROR: Could not open camera {camera_id}")
            sys.exit(1)
        
        # Set resolution - 320x240 is fast and sufficient for hole detection
        self.camera.set(cv2.CAP_PROP_FRAME_WIDTH, 320)
        self.camera.set(cv2.CAP_PROP_FRAME_HEIGHT, 240)
        self.camera.set(cv2.CAP_PROP_BUFFERSIZE, 1)  # Minimize latency
        
        # Warm up camera - first few frames are often dark/corrupted
        print("   Warming up camera...")
        time.sleep(2)
        for i in range(5):
            self.camera.read()  # Discard initial frames
        
        print("   ✓ Camera ready!")
        
        # ========== SERIAL SETUP ==========
        print("\n[2/3] Connecting to Arduino...")
        self.serial = None
        try:
            self.serial = serial.Serial(serial_port, 9600, timeout=1)
            time.sleep(2)  # Wait for Arduino to reset after connection
            print(f"   ✓ Connected to Arduino on {serial_port}")
        except (serial.SerialException, FileNotFoundError) as e:
            print(f"   ⚠️  Arduino not connected: {e}")
            print("   Running in TEST MODE - no Arduino communication")
            print("   (This is fine for calibration and testing)\n")
        
        # ========== DETECTION PARAMETERS ==========
        print("\n[3/3] Loading detection parameters...")
        
        # Hole size constraints (in pixels)
        self.HOLE_DIAMETER_MIN = 20   # Minimum hole diameter
        self.HOLE_DIAMETER_MAX = 100  # Maximum hole diameter
        
        # Expected hole position (center of frame by default)
        self.EXPECTED_X = 160  # X coordinate where hole should be
        self.EXPECTED_Y = 100  # Y coordinate where hole should be
        self.POSITION_TOLERANCE = 100  # How far off-center is acceptable
        
        # Hough Circle detection parameters
        self.BLUR_KERNEL = 5         # Gaussian blur size (must be odd)
        self.HOUGH_DP = 1            # Inverse ratio of accumulator resolution
        self.HOUGH_MIN_DIST = 50     # Minimum distance between circle centers
        self.HOUGH_PARAM1 = 30       # Edge detection threshold (higher = stricter)
        self.HOUGH_PARAM2 = 15       # Circle detection threshold (lower = more sensitive)
        
        # Widget presence detection
        self.WIDGET_THRESHOLD = 10000  # Will be auto-calibrated at startup
        self.BRIGHTNESS_CUTOFF = 120   # Brightness threshold for "dark" objects
        
        # Widget counters for tracking results
        self.goodCount = 0
        self.badCount = 0
        
        print("   ✓ Parameters loaded!")
        
        # ========== AUTO-CALIBRATION ==========
        print("\n[4/4] Auto-calibrating widget detection threshold...")
        print("   Please ensure inspection area is EMPTY")
        print("   Measuring background darkness in 3 seconds...")
        time.sleep(3)
        
        self.auto_calibrate_threshold()
        
        print("\n" + "="*60)
        print("INITIALIZATION COMPLETE")
        print("="*60 + "\n")
    
    def auto_calibrate_threshold(self):
        """
        Automatically calibrate widget detection threshold at startup
        Measures empty platform darkness and sets threshold accordingly
        """
        print("   Taking 5 calibration measurements...")
        
        measurements = []
        for i in range(5):
            # Capture frame
            frame = self.capture_image()
            if frame is None:
                print(f"   Warning: Could not capture calibration frame {i+1}")
                continue
            
            # Measure dark area
            gray = cv2.cvtColor(frame, cv2.COLOR_BGR2GRAY)
            _, thresh = cv2.threshold(gray, self.BRIGHTNESS_CUTOFF, 255, cv2.THRESH_BINARY_INV)
            contours, _ = cv2.findContours(thresh, cv2.RETR_EXTERNAL, cv2.CHAIN_APPROX_SIMPLE)
            
            max_area = 0
            for contour in contours:
                area = cv2.contourArea(contour)
                if area > max_area:
                    max_area = area
            
            measurements.append(max_area)
            print(f"   Measurement {i+1}: {max_area} pixels")
            time.sleep(0.2)
        
        if not measurements:
            print("   ⚠️  Calibration failed - using default threshold")
            return
        
        # Calculate average empty darkness
        avg_empty = sum(measurements) / len(measurements)
        
        # Set threshold = average empty darkness + 10,000 pixel buffer
        # This ensures we detect widgets while ignoring empty platform variations
        self.WIDGET_THRESHOLD = int(avg_empty + 10000)
        
        print(f"\n   ✓ Calibration complete!")
        print(f"   Empty platform darkness: {avg_empty:.0f} pixels (average)")
        print(f"   Widget detection threshold set to: {self.WIDGET_THRESHOLD} pixels")
        print(f"   (Empty + 10,000 pixel buffer)")
    
    def capture_image(self):
        """
        Capture a single frame from the camera
        
        Returns:
            frame: BGR image as numpy array, or None if capture failed
        """
        # Use grab/retrieve for minimal latency (don't use buffered frames)
        self.camera.grab()
        ret, frame = self.camera.retrieve()
        
        if not ret:
            print("ERROR: Could not capture image from camera")
            return None
        return frame
    
    def detect_widget_present(self, frame):
        """
        Detect if a widget is actually present in the frame
        Uses thresholding and contour detection to find dark objects
        
        Args:
            frame: Input BGR image
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

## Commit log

2026-01-09 add image of sorter (not fully assembled)
2026-01-14 upload CAD screenshots
2026-01-14 upload stl files for flip-stop + actuator housing
    [flipper_stopper.stl, linear_actuator_housing.stl]
2026-01-14 add folder for stl files
    [flipper_stopper.stl]
2026-01-14 move actuator housing stl to stl-files folder
    [linear_actuator_housing.stl]
2026-01-14 upload step file for CNCing ramp
    [RampV3.step]
2026-01-14 create folder for cnc files
    [ramp.step]
2026-01-14 create blank .ino file for motor control + leds
2026-01-15 paste-in current arduino code
2026-01-16 Update motor_control.ino
    - changed pins for certain LEDs
    - change angles for flipperFlopper
    - rgb LED now works as intended. Yellow is still similar to green, but oh well
    - actuator retracts when the system is shutdown or all widgets have been sorted
    - flipperStopper now only opens if a widget is detected
    [motor_control.ino]
2026-01-20 Update motor_control.ino
    fix flipperFlopper and ensure that actuator doesn't loop infinitely. Retract actuator when sorting is complete
    [motor_control.ino]
2026-01-20 Update motor_control.ino
    Add in some more code that I forgot to add last time; add the code for flipperFlopper
    [motor_control.ino]
2026-01-20 Added my personal daily documentation, will add images embedded later
    Updated daily documentation with detailed entries for Days 0 to 15, including project planning, coding, testing, and assembly progress.
2026-01-20 Add links to widget detection and Arduino code
2026-01-20 Add older wiring and fritzing diagrams
2026-01-20 Corrected AI acknowledgement in code
    [widget_inspector.py]
2026-01-20 Fix typo in README for Prusa Mk3 3D-Printer
2026-01-20 Rename Widget Mag V2.3.stl to widget-mag-v2.3.stl
    [widget-mag-v2.3.stl]
2026-01-20 Create laser-files
2026-01-20 add flowchart
2026-01-20 Fix image path in daily documentation
    Updated image path for CAD overview screenshot.
2026-01-20 Update CAD models section with links
    Added links to CAD models and files for the project.
2026-01-20 Add CAD overview screenshot to portfolio
    Added a CAD overview screenshot to the portfolio.
2026-01-21 Update general-portfolio.md
    add photos and videos
    - wiring & fritzing
    - flowchart
    - prototype test
    link reflections
2026-01-21 fixed typo (Sonnett → Sonnet)
    [widget_inspector.py]
2026-01-21 Rename 12_5 - Wiring.png to 12_5-Wiring.png
2026-01-21 added older wiring diagrams to documentation
